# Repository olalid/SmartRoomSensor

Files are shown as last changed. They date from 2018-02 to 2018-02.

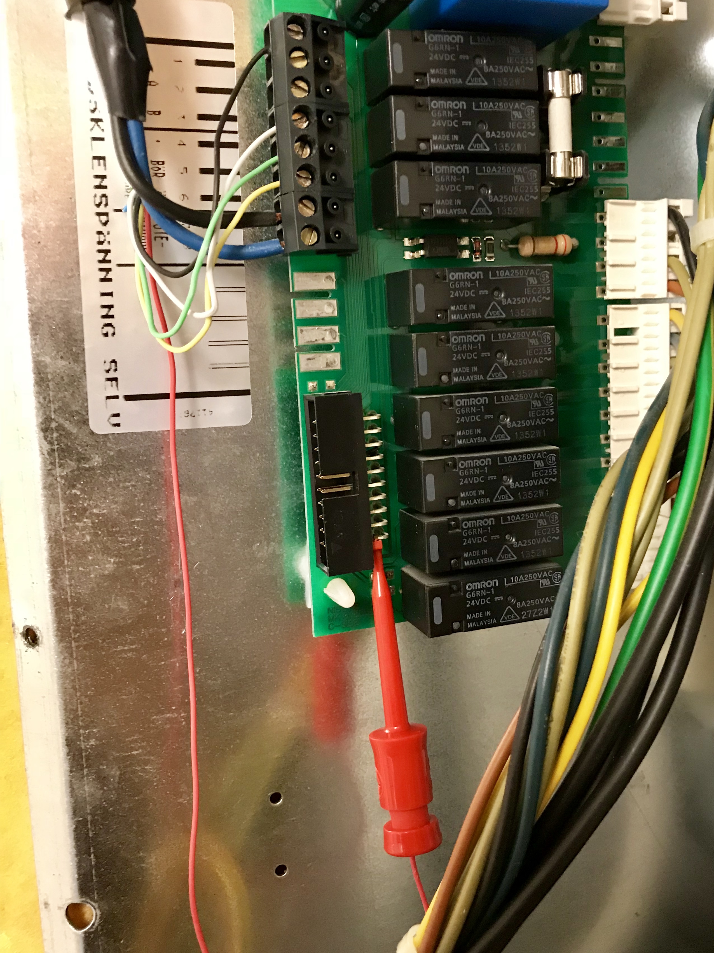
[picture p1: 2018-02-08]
Heatpump connection (Fighter 1215).jpg

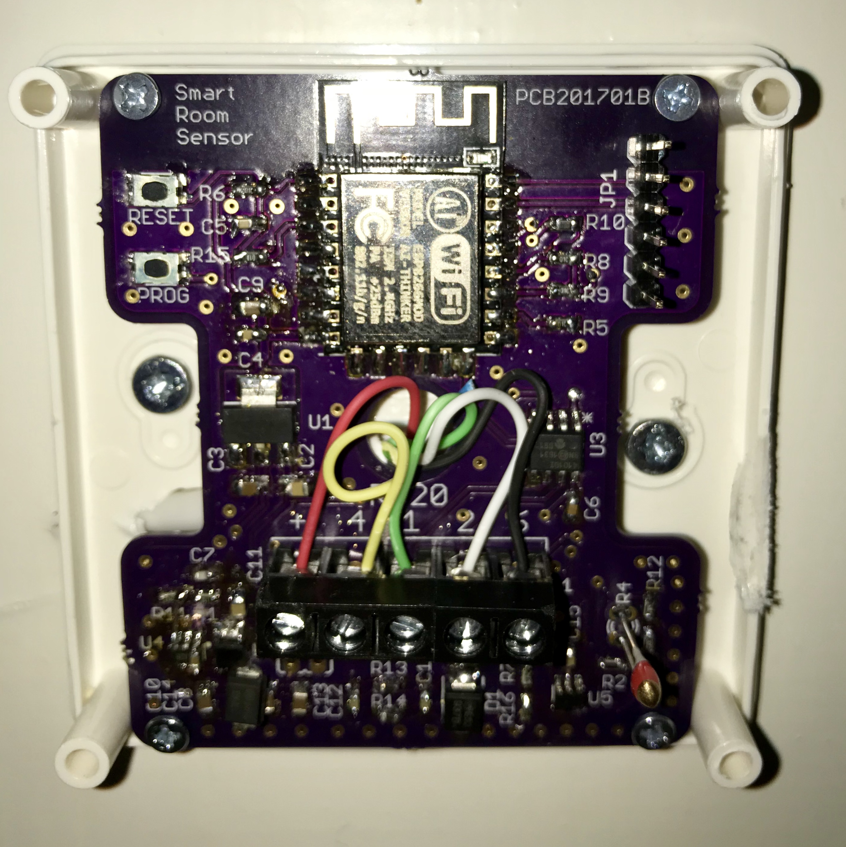
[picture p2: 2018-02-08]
Working prototype.jpg

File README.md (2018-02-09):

# SmartRoomSensor
Smarter replacement for the RG20 room sensor that is an optional extra for some older NIBE heat pumps.

The NIBE RG20 room sensor is a very simple thermostat like device that is connected to a NIBE heatpump and lets you control the temperature in your home more preciesely. A little simplified the original consists of a potentiometer and an NTC resistor.

This replacement version has MQTT support and lets you control the setpoint and read back the current temperature from your home automation system. It also shows the status (heating or idle) of the heatpump.
It connects to the same interface in the heatpump as the RG20 does plus that it steals some power from the heatpump internal PSU (which is around 20-24V).

The hardware is based on on an ESP8266 module, the ESP-12F, combining it with a digital potentiometer for the setpoint control and an NTC resistor for temperature reading. The heatpump power supply has reduced voltage when the heatpump is active, so measuring that voltage makes it possible to detect if the heatpumpt is active or not.

Ths software is based on Arduino and support libraries WiFiManager and PubSubClinet.
A minor modification to PubSubClient is needed, so the modified file is also included.

PS. This is currently work in progress. The uploaded version of schematics and PCB has not been built as a complete prototype, but rather as a patched version of an older PCB revision. I.e. it is not 100% guranteed that it works, even if the risk that it does not should be small.

# Prerequisites
To use this unit, you need to have:

A NIBE heatpump that is compatible with the RG20 room sensor (Doh!)

An MQTT server (like mosquitto) running on a server somewhere.

Some kind of home automation software to display a user interface and possibly atuomate the control of the unit (like Home Assistant).

# Programming
To program the unit, you will need an FTDI USB cable with part number TTL-232R-3V3 (Farnell 1329311). Connect this to the 6-pin header (JP1) and use Arduino (or equivalent) to download the software.

# How to connect to the heatpump
The sensor has a screw terminal that is used to connect wires coming from the heatpump.
The marking on the PCB is the same as the original RG20, plus the additional terminal for the power.
See the installation manual for the original sensor for connection to the heat pump.
http://www.nibe.se/nibedocuments/10013/011022-6.pdf

One thing is different, the power connection is marked with "+" next to its screw terminal on the PCB, but in the heat pump there is no easy accessible terminal for this. So, instead we connect to one of the solder pins on an IDC header that carries the voltage we want to access. A probe clip, such as Farnell part number 523525 makes this easier.

# How to configure the unit
When intially powered up the unit will start in access point mode, creating a WiFi network called "SmartRoomSensor".
Connect to this network using a computer or a smartphone.

Normally a web browser with the configuration interface should open automatically and you can enter the configuration details needed.

You will need to enter the name of your Wifi network, the password, the MQTT server IP or name, MQTT server username/password (if any) and the topics for MQTT.

There are 4 MQTT topics:

tset: the topic the unit will subscribe to get updates on target temperature.

tget: the topic where the unit will publish the configured target temperature.

cget: the topic where the unit will publish the current measured temperature.

mode: the topic where the unit will publish the current heatpump mode (heat or idle).

# Gotchas
The unit wakes up once a minute to set and read temperatures.
Which means that there may be a delay of up to one minute when you set the temperature until it is updated on the heatpumps display.
It may seem unecessary to use sleep mode in this application, but without doing this, the unit would get far to hot and the temperature readings would be useless.

# Known problems
The unit does heat up a bit, compared to the surrounding room temperature, which results in a temperature reading that is 1-2 degrees more than the actual temperature. So the target temperature needs to be increased accordingly. I.e. if you want to have 21 degrees in the room, set 22 or 23 degrees.
This could possibly be compensated by increasing the value of R2 slightly, but this has not (yet) been tested.

# Enclosure
The unit fits in a Supertronic PP42 enclosure. This is also sold as Qubino ZMNHGA1.
See https://www.m.nu/tillbehor/plastbox-vit-med-lufthal-for-vaggmontering

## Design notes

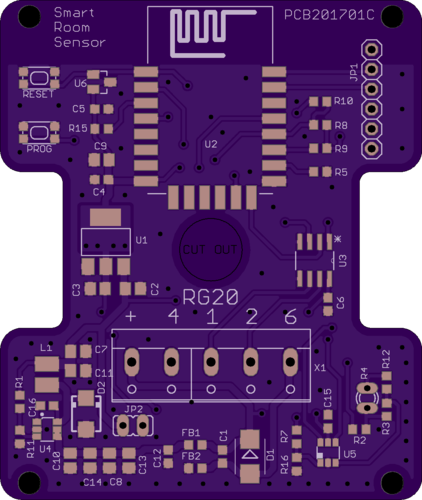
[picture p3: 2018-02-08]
PCBrevC_front.png

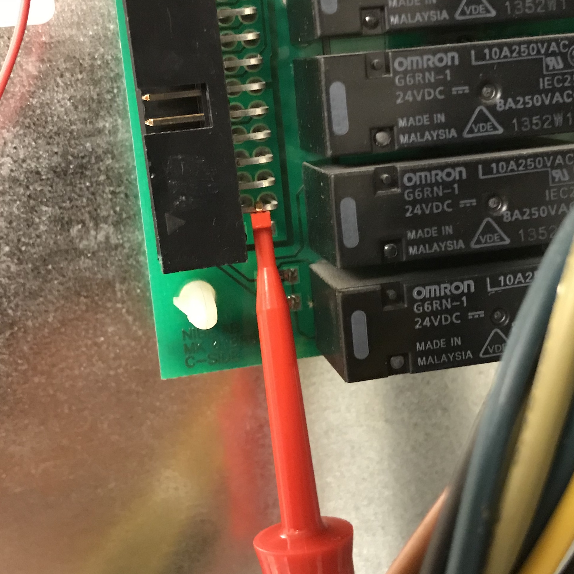
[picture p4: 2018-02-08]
Closeup power connection (Fighter 1215).jpg

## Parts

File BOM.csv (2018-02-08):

Qty | Parts | Value | Description | Farnell order code | m.nu order code
7 | C1, C4, C5, C6, C12, C15, C16 | 100n | CAPACITOR, European symbol | 1759122
6 | R5, R8, R9, R11, R15, R16 | 10k | RESISTOR, European symbol | 2447230
7 | C2, C3, C8, C9, C10, C13, C14 | 10u | CAPACITOR, European symbol | 2611943
2 | R2, R10 | 169R | RESISTOR, European symbol | 2303081
1 | D1 | 1SMB5937BT3G | Z-Diode | 1431179
1 | JP2 | 2 pin header | JUMPER | 1593411
1 | R4 | 2.2k | PHILIPS NTC | 1187025
1 | R3 | 20k | RESISTOR, European symbol | 2447293
2 | C7, C11 | 22u | CAPACITOR, European symbol | 2309030
1 | R7 | 270k | RESISTOR, European symbol | 2447313
1 | X1 | 5 x Screw clamp | WAGO SREW CLAMP | 1717004
1 | R1 | 56k | RESISTOR, European symbol | 2303215
1 | JP1 | 6 pin header | PIN HEADER | 1593415
1 | R12 | 6k8 | RESISTOR, European symbol | 2447427
1 | U2 | ESP-12F | ESP12F Module |  | ESP12F
2 | FB1, FB2 | Ferrite | RESISTOR, European symbol | 1635706
1 | U4 | LMR14206 | LMR14206 SIMPLE SWITCHER® 42Vin, 0.6A Step-Down Voltage Regulator in SOT-23 | 2064681
1 | U6 | MCP130T-315I/TT | Reset circuit | 9758470
1 | U3 | MCP41010-I/SN | Digital POT | 9758607
1 | L1 | ME3220-153KLB | Inductor | 2287926
1 | U1 | REG1117 | 800mA and 1A Low Dropout (LDO) Positive Regulator | 1825376
1 | D2 | S1A | Schottky diode | 1559148
1 | U5 | SN74LVC1G3157DBVR | Single-Pole, Double-Throw Analog Switch | 1470910
2 | SW1, SW2 | SPST_TACT-KMR2 | SMT 6mm switch, EVQQ2 series | 1437636

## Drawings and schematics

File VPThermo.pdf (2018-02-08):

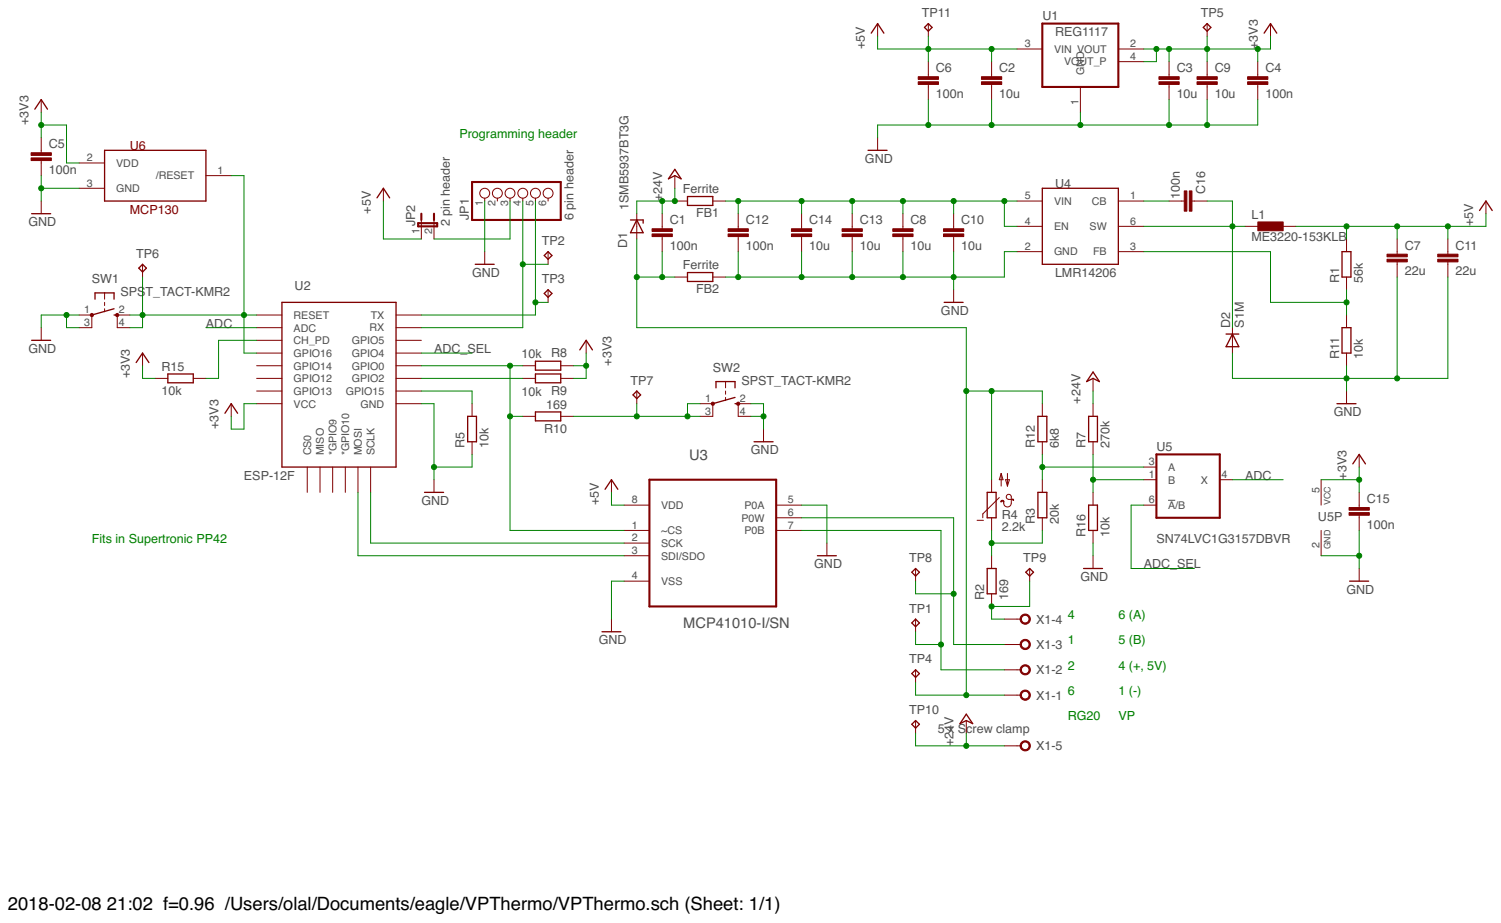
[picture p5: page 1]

2018-02-08 21:02 f=0.96 /Users/olal/Documents/eagle/VPThermo/VPThermo.sch (Sheet: 1/1)

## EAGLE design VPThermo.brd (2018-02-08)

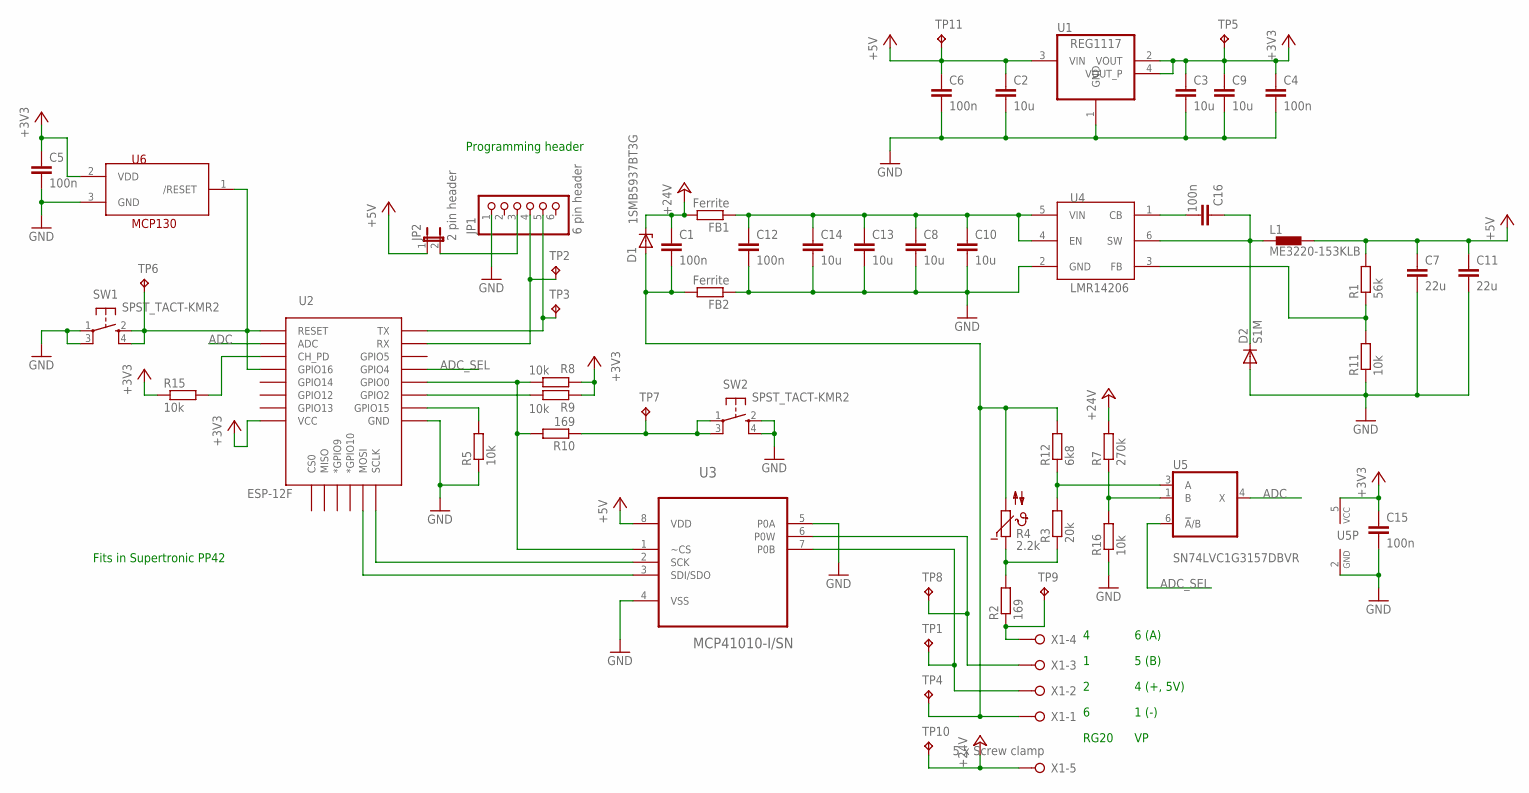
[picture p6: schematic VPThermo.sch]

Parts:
C1, C4, C5, C6, C12, C15, C16: 100n; C0603
C2, C3, C8, C9, C10, C13, C14: 10u; C0805
C7, C11: 22u; C0805
D1: 1SMB5937BT3G; SMB
D2: S1M; SMA
FB1, FB2: Ferrite; R0603
JP1: 6 pin header; 1X06
JP2: 2 pin header; JP1
L1: ME3220-153KLB; SDR0302
R1: 56k; R0603
R2, R10: 169; R0603
R3: 20k; R0603
R4: 2.2k; P640
R5, R8, R9, R11, R15, R16: 10k; R0603
R7: 270k; R0603
R12: 6k8; R0603
SW1, SW2: SPST_TACT-KMR2; KMR2
TP1, TP2, TP3, TP4, TP5, TP6, TP7, TP8, TP9, TP10, TP11: TPB1,27; B1,27
U1: REG1117; SOT223
U2: ESP-12F; ESP12E-SMD
U3: MCP41010-I/SN; SOIC127P600X175-8N; MPN MCP41010-I/SN
U4: LMR14206; SOT-23-6
U5: SN74LVC1G3157DBVR; DBV_R-PDSO-G6
U6: MCP130; SOT23
X1: 5 x Screw clamp; W237-5P

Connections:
+3V3: C3.1, C4.1, C5.1, C9.1, C15.1, R8.1, R9.1, R15.1, TP5.TP, U1.2 (VOUT), U1.4 (VOUT_P), U2.VCC, U5.5 (VCC), U6.2 (VDD)
+5V: C2.1, C6.1, C7.1, C11.1, JP2.1, L1.2, R1.2, TP11.TP, U1.3 (VIN), U3.8 (VDD)
+24V: C1.1, D1.C, FB1.2, R7.2, TP10.TP, X1.5
ADC: U2.ADC, U5.4 (X)
ADC_SEL: U2.GPIO4, U5.6 (!A!/B)
GND: C2.2, C3.2, C4.2, C5.2, C6.2, C7.2, C8.2, C9.2, C10.2, C11.2, C12.2, C13.2, C14.2, C15.2, D2.A, FB2.1, JP1.1, R5.1, R11.1, R16.1, SW1.1, SW1.3 (P1), SW2.2 (S), SW2.4 (S1), U1.1 (GND), U2.GND, U3.4 (VSS), U3.5 (P0A), U4.2 (GND), U5.2 (GND), U6.3 (GND)
unnamed: R10.1, SW2.1, SW2.3 (P1), TP7.TP
unnamed: U2.MOSI, U3.3 (SDI/SDO)
unnamed: C16.2, U4.1 (CB)
unnamed: JP1.3, JP2.2
unnamed: U2.SCLK, U3.2 (SCK)
unnamed: JP1.4, TP2.TP, U2.RXD0 (RX)
unnamed: JP1.5, TP3.TP, U2.TXD0 (TX)
unnamed: R3.2, R12.1, U5.3 (A)
unnamed: TP8.TP, U3.6 (P0W), X1.3
unnamed: R2.2, R3.1, R4.1
unnamed: R2.1, TP9.TP, X1.4
unnamed: R5.2, U2.GPIO15
unnamed: C8.1, C10.1, C12.1, C13.1, C14.1, FB1.1, U4.4 (EN), U4.5 (VIN)
unnamed: TP1.TP, U3.7 (P0B), X1.2
unnamed: R8.2, R10.2, U2.GPIO0, U3.1 (~CS)
unnamed: R9.2, U2.GPIO2
unnamed: C1.2, D1.A, FB2.2, R4.2, R12.2, TP4.TP, X1.1
unnamed: R1.1, R11.2, U4.3 (FB)
unnamed: R15.2, U2.CH_PD
unnamed: R7.1, R16.2, U5.1 (B)
unnamed: SW1.2 (S), SW1.4 (S1), TP6.TP, U2.GPIO16, U2.RESET, U6.1 (/RESET)
unnamed: C16.1, D2.C, L1.1, U4.6 (SW)

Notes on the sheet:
RG20
1 (-)
4 (+, 5V)
5 (B)
6 (A)
Fits in Supertronic PP42
Programming header

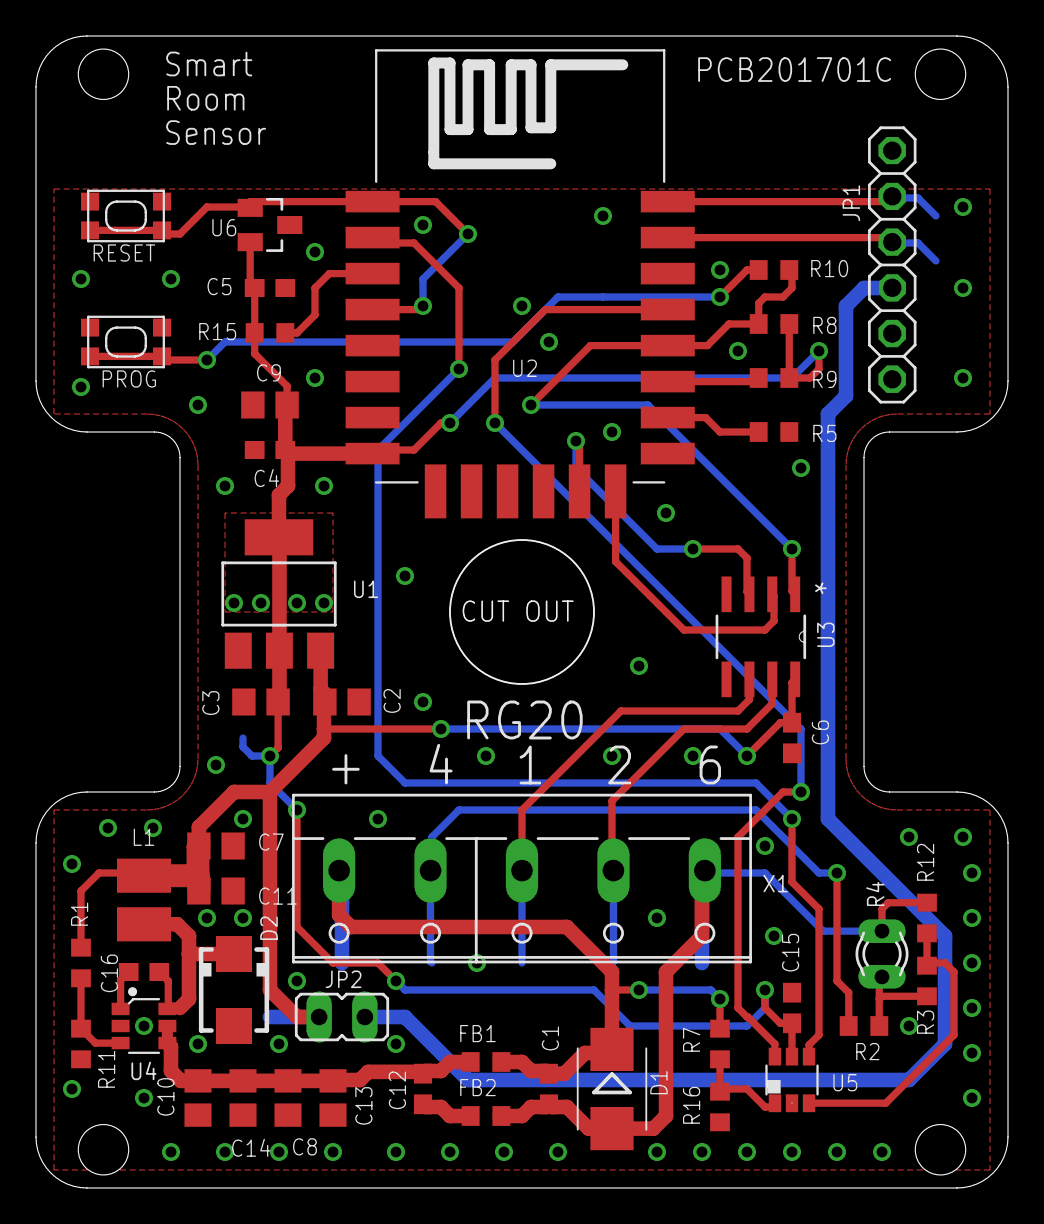
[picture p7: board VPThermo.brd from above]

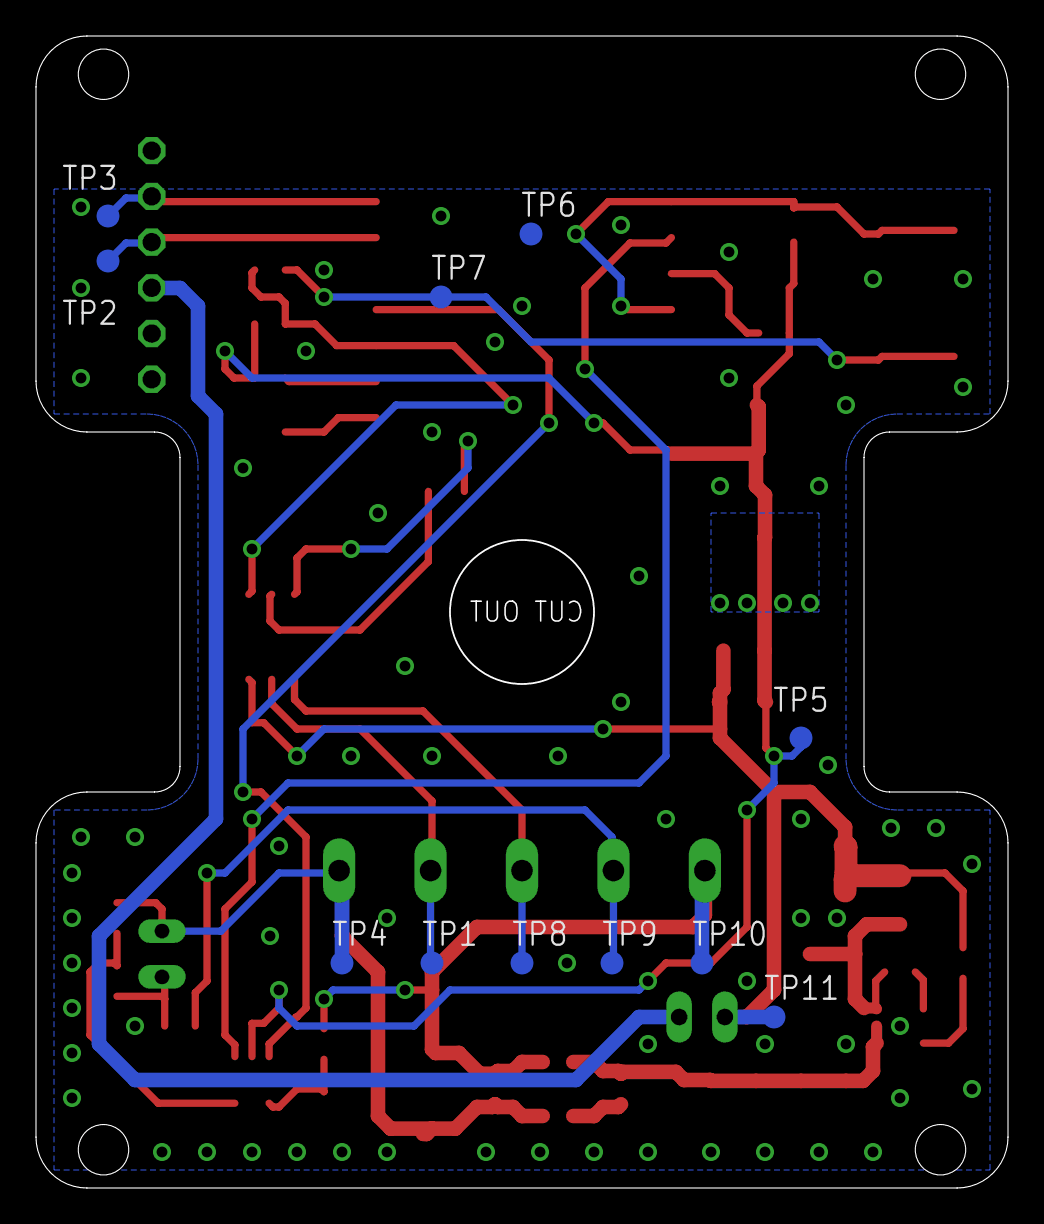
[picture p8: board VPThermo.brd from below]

Board: 2 copper layers, 54.0 x 64.0 mm, 56 parts (11 on the bottom side), 28 nets.

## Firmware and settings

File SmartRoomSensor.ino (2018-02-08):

//#include <ArduinoOTA.h>

#include <FS.h>                   //this needs to be first, or it all crashes and burns...

#include <ESP8266WiFi.h>          //https://github.com/esp8266/Arduino
#include <SPI.h>
//needed for library
#include <DNSServer.h>
#include <ESP8266WebServer.h>
#include <WiFiManager.h>          //https://github.com/tzapu/WiFiManager

#include <ArduinoJson.h>          //https://github.com/bblanchon/ArduinoJson
#define MQTT_VERSION MQTT_VERSION_3_1
#include <PubSubClient.h>         // NOTE: PubSubClient.cpp library needs to be patched to correctly support receiving retained messages
                                  // at connect (remove the clean session flag).
                                  // Add the line: v = v & 0xFD;
                                  // PubSubClient::connect
                                  // See https://github.com/knolleary/pubsubclient/issues/174

//#define DEBUG_CONFIG 1
#define ADC_SEL_PIN 4

WiFiClient espClient;
PubSubClient client(espClient);
long lastMsg = 0;
char msg[50];
int potVal = 0;
int adcVal = 0;
const int spiCSPin = 15;
long targetTemp = 0;

SPISettings settingsSPI(1000000, MSBFIRST, SPI_MODE0); 

//define your default values here, if there are different values in config.json, they are overwritten.
char mqtt_server[40];
char mqtt_port[6] = "1883";
char mqtt_user[64] = "";
char mqtt_pass[64] = "";
char mqtt_tset_topic[64] = "sensor/heatpump/target_temp_set";
char mqtt_tget_topic[64] = "sensor/heatpump/target_temp_get";
char mqtt_cget_topic[64] = "sensor/heatpump/current_temp_get";
char mqtt_mode_topic[64] = "sensor/heatpump/mode";

//flag for saving data
bool shouldSaveConfig = false;
bool didReceiveMQTT = false;

// Callback notifying us of the need to save config
void saveConfigCallback () {
  Serial.println("Should save config");
  shouldSaveConfig = true;
}

// Support function to convert string to integer
int natoi(char *s, int n)
{
    int x = 0;
    while(isdigit(s[0]) && n--)
    {
        x = x * 10 + (s[0] - '0');      
        s++;
    }
    return x;
}

// Subscription callback for MQTT library
void mqttCallback(char* topic, byte* payload, unsigned int length) {

  uint16 setVal;

  // Print what we received
  Serial.print("Message arrived [");
  Serial.print(topic);
  Serial.print("] ");
  for (int i = 0; i < length; i++) {
    Serial.print((char)payload[i]);
  }
  Serial.println();

  // Convert the value to integer
  targetTemp = natoi((char *)payload, length);
  // Check that we are within our limits
  if(targetTemp < 5)
    targetTemp = 5;
  if(targetTemp > 30)
    targetTemp = 30;

  // Convert to potentiometer value
  setVal = 0x1300 | (((89*(30-targetTemp)+145)/10) & 0xff);
  
  snprintf(msg, 75, "Set: %ld pot: %ld", targetTemp, setVal);
  Serial.println(msg);
  SPI.beginTransaction(settingsSPI);
  SPI.write16(setVal);
  SPI.endTransaction();

  // Publish back to acknowledge that we have received and set the value
  snprintf(msg, 75, "%ld", targetTemp);
  client.publish(mqtt_tget_topic, msg, true);

  // Set the flag to tell our main code that we are done
  didReceiveMQTT = true;
  
}

void setup() {

  int i;
  long bootTime;
  boolean r;
  
  bootTime = millis();
  
  // Init serial port
  Serial.begin(74880);
  Serial.println();
  Serial.println("Smart Room Sensor reboot");

  // Init I/O and select ADC input
  pinMode(ADC_SEL_PIN, OUTPUT);
  digitalWrite(ADC_SEL_PIN, LOW);

  
  //clean FS, for testing
#ifdef DEBUG_CONFIG
  Serial.println("Debug mode, erasing FS");
  SPIFFS.format();
#endif

  //Try to read configuration from FS json

  //ESP.deepSleep(1*1e6);
  
  if (SPIFFS.begin()) {
    Serial.println("mounted file system");
    if (SPIFFS.exists("/config.json")) {
      //file exists, reading and loading
      Serial.println("reading config file");
      File configFile = SPIFFS.open("/config.json", "r");
      if (configFile) {
        Serial.println("opened config file");
        size_t size = configFile.size();
        // Allocate a buffer to store contents of the file.
        std::unique_ptr<char[]> buf(new char[size]);

        configFile.readBytes(buf.get(), size);
        DynamicJsonBuffer jsonBuffer;
        JsonObject& json = jsonBuffer.parseObject(buf.get());
        //json.printTo(Serial);
        if (json.success()) {
          Serial.println("\nparsed json");

          strcpy(mqtt_server, json["mqtt_server"]);
          strcpy(mqtt_port, json["mqtt_port"]);
          strcpy(mqtt_user, json["mqtt_user"]);
          strcpy(mqtt_pass, json["mqtt_pass"]);
          strcpy(mqtt_tset_topic, json["mqtt_tset_topic"]);
          strcpy(mqtt_tget_topic, json["mqtt_tget_topic"]);
          strcpy(mqtt_cget_topic, json["mqtt_cget_topic"]);
          strcpy(mqtt_mode_topic, json["mqtt_mode_topic"]);
          
        } else {
          Serial.println("failed to load json config");
        }
      }
    }
  } else {
    Serial.println("failed to mount FS");
  }
  //end read
  
  // The extra parameters to be configured (can be either global or just in the setup)
  // After connecting, parameter.getValue() will get you the configured value
  // id/name placeholder/prompt default length
  WiFiManagerParameter custom_mqtt_server("server", "mqtt server", mqtt_server, 40);
  WiFiManagerParameter custom_mqtt_port("port", "mqtt port", mqtt_port, 6);
  WiFiManagerParameter custom_mqtt_user("user", "mqtt username", mqtt_user, 40);
  WiFiManagerParameter custom_mqtt_pass("pass", "mqtt password", mqtt_pass, 40);
  WiFiManagerParameter custom_mqtt_tset_topic("tset_topic", "mqtt tset topic", mqtt_tset_topic, 62);
  WiFiManagerParameter custom_mqtt_tget_topic("tget_topic", "mqtt tget topic", mqtt_tget_topic, 62);
  WiFiManagerParameter custom_mqtt_cget_topic("cget_topic", "mqtt cget topic", mqtt_cget_topic, 62);
  WiFiManagerParameter custom_mqtt_mode_topic("mode_topic", "mqtt mode topic", mqtt_mode_topic, 62);
  
  //WiFiManager
  //Local intialization. Once its business is done, there is no need to keep it around
  WiFiManager wifiManager;

  //set config save notify callback
  wifiManager.setSaveConfigCallback(saveConfigCallback);

  //set static ip
  //wifiManager.setSTAStaticIPConfig(IPAddress(10,0,1,99), IPAddress(10,0,1,1), IPAddress(255,255,255,0));
  
  //add all your parameters here
  wifiManager.addParameter(&custom_mqtt_server);
  wifiManager.addParameter(&custom_mqtt_port);
  wifiManager.addParameter(&custom_mqtt_user);
  wifiManager.addParameter(&custom_mqtt_pass);
  wifiManager.addParameter(&custom_mqtt_tset_topic);
  wifiManager.addParameter(&custom_mqtt_tget_topic);
  wifiManager.addParameter(&custom_mqtt_cget_topic);
  wifiManager.addParameter(&custom_mqtt_mode_topic);

  //reset settings - for testing
#ifdef DEBUG_CONFIG
  wifiManager.resetSettings();
#endif

  //set minimu quality of signal so it ignores AP's under that quality
  //defaults to 8%
  //wifiManager.setMinimumSignalQuality();
  
  //sets timeout until configuration portal gets turned off
  //useful to make it all retry or go to sleep
  //in seconds
  wifiManager.setTimeout(30);

  //fetches ssid and pass and tries to connect
  //if it does not connect it starts an access point with the specified name
  //here  "SmartRoomSensor"
  //and goes into a blocking loop awaiting configuration
  if (!wifiManager.autoConnect("SmartRoomSensor")) {
    Serial.println("failed to connect and hit timeout. Sleeping for 10 seconds.");
    ESP.deepSleep(10*1e6);
  }

  //if you get here you have connected to the WiFi
  Serial.println("WiFi connected");

  //read updated parameters
  strcpy(mqtt_server, custom_mqtt_server.getValue());
  strcpy(mqtt_port, custom_mqtt_port.getValue());
  strcpy(mqtt_user, custom_mqtt_user.getValue());
  strcpy(mqtt_pass, custom_mqtt_pass.getValue());
  strcpy(mqtt_tset_topic, custom_mqtt_tset_topic.getValue());
  strcpy(mqtt_tget_topic, custom_mqtt_tget_topic.getValue());
  strcpy(mqtt_cget_topic, custom_mqtt_cget_topic.getValue());
  strcpy(mqtt_mode_topic, custom_mqtt_mode_topic.getValue());

  //save the custom parameters to FS if needed
  if (shouldSaveConfig) {
    Serial.println("saving config");
    DynamicJsonBuffer jsonBuffer;
    JsonObject& json = jsonBuffer.createObject();
    json["mqtt_server"] = mqtt_server;
    json["mqtt_port"] = mqtt_port;
    json["mqtt_user"] = mqtt_user;
    json["mqtt_pass"] = mqtt_pass;
    json["mqtt_tset_topic"] = mqtt_tset_topic;
    json["mqtt_tget_topic"] = mqtt_tget_topic;
    json["mqtt_cget_topic"] = mqtt_cget_topic;
    json["mqtt_mode_topic"] = mqtt_mode_topic;

    File configFile = SPIFFS.open("/config.json", "w");
    if (!configFile) {
      Serial.println("failed to open config file for writing");
    }

    json.printTo(Serial);
    json.printTo(configFile);
    configFile.close();
    //end save
  }

  // We are connected, print the local IP
  Serial.println("local ip");
  Serial.println(WiFi.localIP());

  // MQTT client init
  client.setServer(mqtt_server, atoi(mqtt_port));
  client.setCallback(mqttCallback);

  // Init the SPI interface
  SPI.pins(6, 7, 8, 0);
  SPI.begin();

  // Connect to the MQTT server
  // If it fails we will go to sleep again and start over 
 
  Serial.print("Attempting MQTT connection...");
  // Attempt to connect
  if(strlen(mqtt_user)) {
    // If username is given, connect with username password
    r = client.connect("smartroomsensor", mqtt_user, mqtt_pass);
  } else {  
    // No username given
    r = client.connect("smartroomsensor");
  }
  if (r) {
    Serial.println("connected");
    // ... and subscribe
    Serial.print("Subscribe to: ");
    Serial.println(mqtt_tset_topic);
    client.subscribe(mqtt_tset_topic);
  } else {
    Serial.print("failed, rc=");
    Serial.print(client.state());
    Serial.println(" trying again in 10 seconds. Going to sleep.");
    ESP.deepSleep(10*1e6);
  }
  // Library process
  client.loop();

  // Read current temperature frpm ADC
  adcVal = analogRead(A0);
  // Select the other input to use later
  digitalWrite(ADC_SEL_PIN, HIGH);
  snprintf(msg, 75, "Analog input: %ld", adcVal);
  Serial.println(msg);

  // Publish current temperature to the MQTT server
  //adcVal = (607.84091-(0.719697*((double)adcVal)))+1;
  adcVal = (613.84091-(0.719697*((double)adcVal)))+1;
  snprintf (msg, 75, "%ld.", adcVal/10);
  if(adcVal % 10 >= 5)
    strcat(msg, "5");
  else
    strcat(msg, "0");
  Serial.print("Publish message: ");
  Serial.println(msg);
  client.publish(mqtt_cget_topic, msg, true);

  // Read current supply voltage from the ADC
  adcVal = analogRead(A0);
  snprintf(msg, 75, "Analog input: %ld", adcVal);
  Serial.println(msg);
  
  // Publish current mode
  //adcVal = (adcVal * 280) / 1024;
  if(adcVal > 762)
    client.publish(mqtt_mode_topic, "idle", true);
  else
    client.publish(mqtt_mode_topic, "heat", true);
  
  long start, now;
  start = millis();
  for(;;) {
    client.loop();
    now = millis();
    if(didReceiveMQTT)
      break;
    if(now - start > 5000)
      break;
  }
  client.loop();
  client.disconnect();
  client.loop();
  while(client.connected())
    client.loop();

  // Give the MQTT server some time to really disconnect...
  delay(500);
  
  bootTime = millis() - bootTime;
  snprintf(msg, 75, "Active time: %ld msecs", bootTime);
  Serial.println(msg);
  Serial.println("Now going to sleep.");
  if(bootTime > 59e3)
    ESP.deepSleep(60*1e6);

  // Calculate how long to sleep so that we wake up with approximately 60 second intervals
  ESP.deepSleep((60-(bootTime/1000))*1e6);
  
}

void loop() {
  // No code here since the code only runs once and then goes to sleep.

}

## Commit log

2018-02-08 Revision C
    [VPThermo.brd, VPThermo.sch]
2018-02-08 Image of rev C PCB
2018-02-08 Bill of Materials
    [BOM.csv]
